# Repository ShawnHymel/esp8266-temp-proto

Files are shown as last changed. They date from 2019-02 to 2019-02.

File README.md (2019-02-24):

ESP8266 Temperature Sensor Prototype
====================================

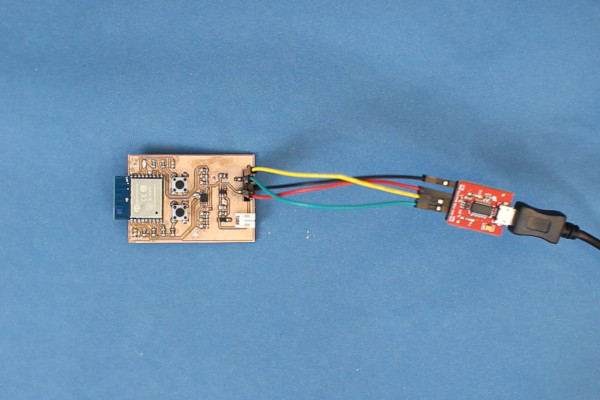
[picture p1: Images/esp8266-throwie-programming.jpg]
ESP8266-WROOM-02 Temperature Sensor Throwie


This is a quick prototype designed for the Bantam Tools Desktop PCB Milling Machine. It uses an ESP8266-WROOM-02 module connected to an MCP9808 temperature sensor. It will run off a single-cell LiPo battery, but there is no protection, undervoltage detection, or charge circuitry onboard. The idea is simple: read from temperature sensor and post to a server at regular intervals. It should work as a simple, IoT Temperature Sensor Throwie.

To Build
--------

Schematic found at *Hardware/esp8266-temp-sensor-schematic.pdf*.

Gerbers are found in the *Hardware/gerbers* folder. Mill them or send them off to a PCB fab house. If you want solder mask and silk screen, you'll have to run your own Gerbers from within KiCad. Also, I didn't move the REFDES labels around to make them look nice (since I was making this board on a mill). You'll probably want to do that, too.

Bill of Materials (BOM) is *Hardware/esp8266-temp-proto_BOM.xlsx*. Buy stuff listed in that. Assemble board.

To Program ESP8266
------------------

Connect 3.3V USB-to-Serial adapter to header on board:

| USB-to-Serial | ESP8266 Board |
| --- | --- |
| 3.3 V | 3.3 V |
| GND | GND |
| TX | RX |
| RX | TX |

Press and hold both buttons. Release RESET button first for 1 second and then release PROG button. This will put the ESP8266 into programming/bootloader mode.

Add `http://arduino.esp8266.com/stable/package_esp8266com_index.json` to the Additional Boards Manager URLs in *File > Preferences in Arduino*. Install *esp8266 by ESP8266 Community* in Boards Manager.

Open *Firmware/esp8266-temp-get/esp8266-temp-get.ino* and change SSID and WiFi password to your network's credentials. Change `hostname` to your computer's IP address. Upload to ESP8266-WROOM-02.

To Run Server
-------------

Install Python (this was tested on Python 3.7). Run *Software/test-srever.py*. With your server running and ESP8266 powered, you should see temperature posted every ~10 seconds.

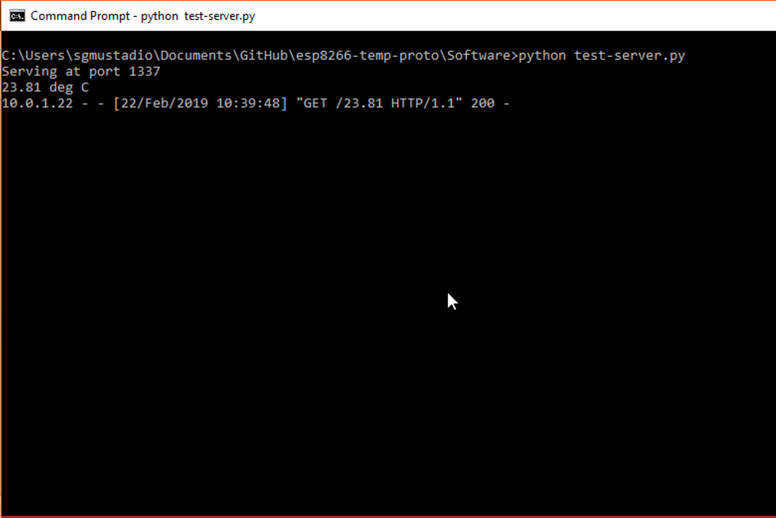
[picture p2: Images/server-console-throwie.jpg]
Temperature Sensor Throwie posting to server console


LED Blink Codes
---------------

Slow blink: Connecting to WiFi

Fast blink: Error

Steady on: Posting to server

License
-------

The hardware (schematic and PCB layout) is licensed under Creative Commons 4.0 BY [CC BY 4.0](https://creativecommons.org/licenses/by/4.0/).

The software (Arduino and Python code found in Firmware/ and Software/) is [Beerware](https://en.wikipedia.org/wiki/Beerware).

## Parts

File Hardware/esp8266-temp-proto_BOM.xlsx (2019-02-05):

Reference | Quantity | Value | Footprint | MPN | Price | Total Price | Part Page
C1 | 1 | 1uF | Capacitor_SMD:C_0805_2012Metric_Pad1.15x1.40mm_HandSolder | 08053C105KAT2A | $0.29 | $0.29 | https://www.digikey.com/product-detail/en/avx-corporation/08053C105KAT2A/478-5030-1-ND/1888241
C2 | 1 | 2.2uF | Capacitor_SMD:C_0805_2012Metric_Pad1.15x1.40mm_HandSolder | 08053C225K4Z2A | $0.47 | $0.47 | https://www.digikey.com/product-detail/en/avx-corporation/08053C225K4Z2A/478-12141-1-ND/9374710
C3 C4 | 2 | 0.1uF | Capacitor_SMD:C_0805_2012Metric_Pad1.15x1.40mm_HandSolder | 08055C104KAT2A | $0.22 | $0.44 | https://www.digikey.com/product-detail/en/avx-corporation/08055C104KAT2A/478-1395-1-ND/564427
D1 | 1 | D_Schottky | Diode_SMD:D_SOD-123F | MBR120VLSFT3G | $0.42 | $0.42 | https://www.digikey.com/product-detail/en/on-semiconductor/MBR120VLSFT3G/MBR120VLSFT3GOSCT-ND/3487322
D2 | 1 | LTST-C171KRKT | digikey-footprints:0805 | LTST-C171KRKT | $0.31 | $0.31 | https://www.digikey.com/product-detail/en/lite-on-inc/LTST-C171KRKT/160-1427-1-ND/386800
J1 | 1 | Conn_01x05 | Connector_PinSocket_2.54mm:PinSocket_1x05_P2.54mm_Vertical_SMD_Pin1Left | NPTC051KFXC-RC | $0.86 | $0.86 | https://www.digikey.com/product-detail/en/sullins-connector-solutions/NPTC051KFXC-RC/S5597-ND/776055
J2 | 1 | S2B-PH-K-S(LF)(SN) | S2B-PH-K-S_LF__SN_:JST_S2B-PH-K-S(LF)(SN) | S2B-PH-K-S(LF)(SN) | $0.17 | $0.17 | https://www.digikey.com/product-detail/en/jst-sales-america-inc/S2B-PH-K-S-LF-SN/455-1719-ND/926626
R1 | 1 | 220 | Resistor_SMD:R_0805_2012Metric_Pad1.15x1.40mm_HandSolder | RC0805FR-07220RL | $0.10 | $0.10 | https://www.digikey.com/product-detail/en/yageo/RC0805FR-07220RL/311-220CRCT-ND/730688
R10 R11 R12 R13 R2 R5 R7 R8 R9 | 9 | 10k | Resistor_SMD:R_0805_2012Metric_Pad1.15x1.40mm_HandSolder | RC0805FR-0710KL | $0.10 | $0.90 | https://www.digikey.com/product-detail/en/yageo/RC0805FR-0710KL/311-10.0KCRCT-ND/730482
R3 R4 | 2 | 4.7k | Resistor_SMD:R_0805_2012Metric_Pad1.15x1.40mm_HandSolder | RC0805FR-074K7L | $0.10 | $0.20 | https://www.digikey.com/product-detail/en/yageo/RC0805FR-074K7L/311-4.70KCRCT-ND/730876
R6 | 1 | 1k | Resistor_SMD:R_0805_2012Metric_Pad1.15x1.40mm_HandSolder | RC0805FR-071KL | $0.10 | $0.10 | https://www.digikey.com/product-detail/en/yageo/RC0805FR-071KL/311-1.00KCRCT-ND/730391
S1 S2 | 2 | 1825910-6 | digikey-footprints:Switch_Tactile_THT_6x6mm | 1825910-6 | $0.11 | $0.22 | https://www.digikey.com/product-detail/en/te-connectivity-alcoswitch-switches/1825910-6/450-1650-ND/1632536
U1 | 1 | AP2112K-3.3TRG1 | AP2112K-3.3TRG1:SOT95P285X140-5N | AP2112K-3.3TRG1 | $0.49 | $0.49 | https://www.digikey.com/product-detail/en/diodes-incorporated/AP2112K-3.3TRG1/AP2112K-3.3TRG1DICT-ND/4505257
U2 | 1 | MCP9808-E_MS | MCP9808-E&slash_MS:MCP9808-E&slash_MS | MCP9808-E/MS | $1.16 | $1.16 | https://www.digikey.com/product-detail/en/microchip-technology/MCP9808-E-MS/MCP9808-E-MS-ND/2802083
U3 | 1 | ESP-WROOM-02 | ESP-WROOM-02:MODULE_ESP-WROOM-02 | ESP-WROOM-02 | $2.70 | $2.70 | https://www.digikey.com/product-detail/en/espressif-systems/ESP-WROOM-02/1904-1009-1-ND/8544304
 |  |  |  |  | Total: | $8.83

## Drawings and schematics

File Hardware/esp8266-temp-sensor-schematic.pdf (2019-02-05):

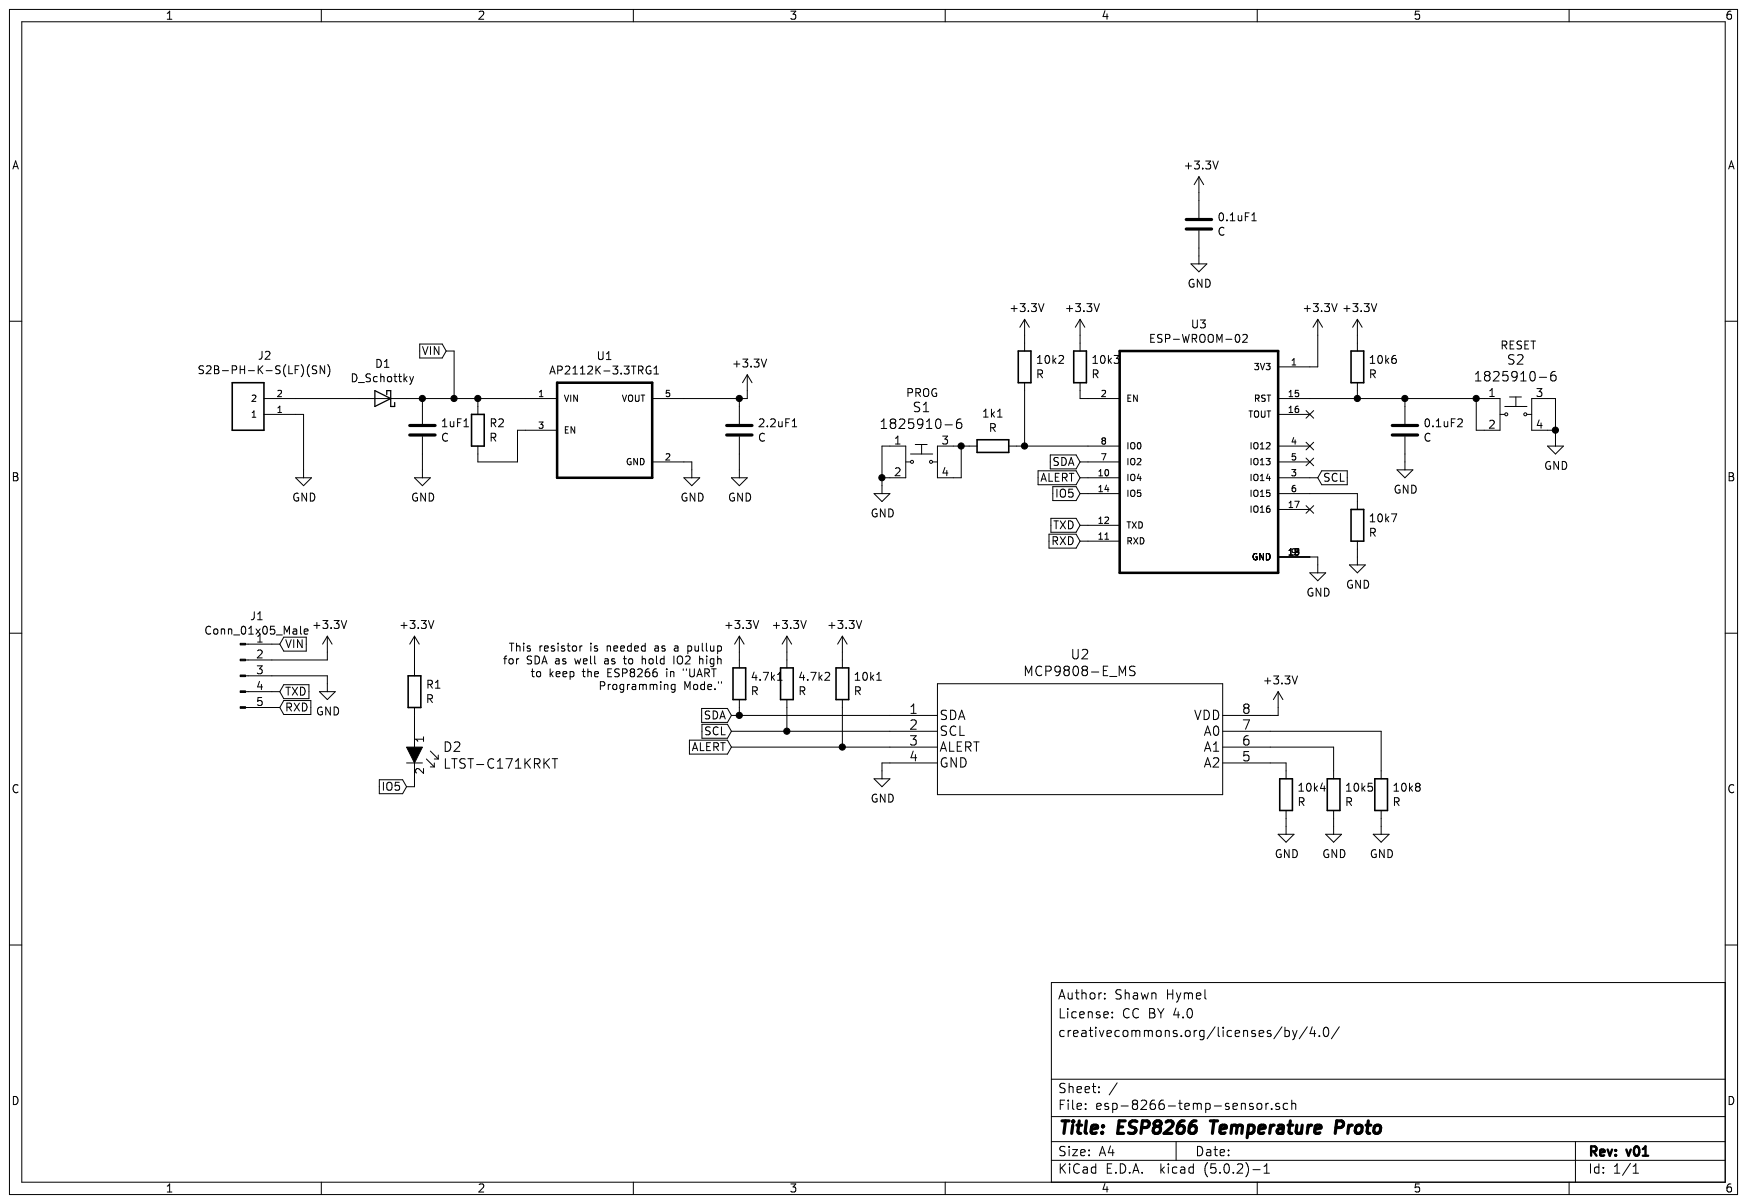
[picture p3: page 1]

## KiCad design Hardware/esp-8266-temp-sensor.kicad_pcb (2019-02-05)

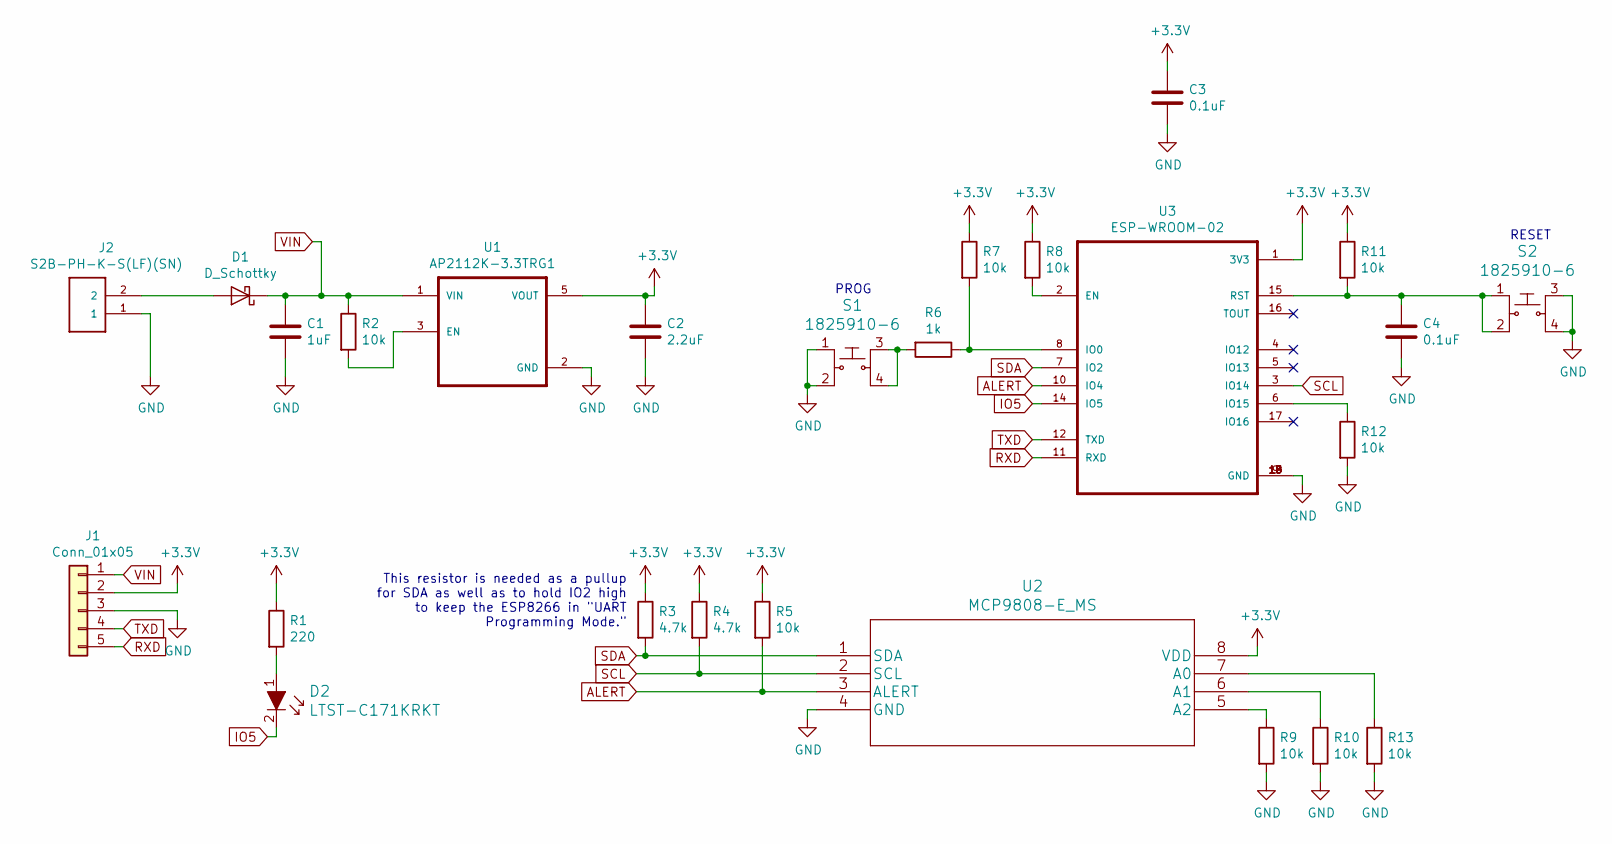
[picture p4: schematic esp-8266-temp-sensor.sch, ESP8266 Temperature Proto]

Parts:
C1: 1uF; C_0805_2012Metric_Pad1.15x1.40mm_HandSolder
C2: 2.2uF; C_0805_2012Metric_Pad1.15x1.40mm_HandSolder
C3, C4: 0.1uF; C_0805_2012Metric_Pad1.15x1.40mm_HandSolder
D1: D_Schottky; D_SOD-123F
D2: LTST-C171KRKT; 0805; MPN LTST-C171KRKT; Digi-Key_PN 160-1427-1-ND
J1: Conn_01x05; PinSocket_1x05_P2.54mm_Vertical_SMD_Pin1Left
J2: S2B-PH-K-S(LF)(SN); JST_S2B-PH-K-S(LF)(SN)
R1: 220; R_0805_2012Metric_Pad1.15x1.40mm_HandSolder
R2, R5, R7, R8, R9, R10, R11, R12, R13: 10k; R_0805_2012Metric_Pad1.15x1.40mm_HandSolder
R3, R4: 4.7k; R_0805_2012Metric_Pad1.15x1.40mm_HandSolder
R6: 1k; R_0805_2012Metric_Pad1.15x1.40mm_HandSolder
S1, S2: 1825910-6; Switch_Tactile_THT_6x6mm; MPN 1825910-6; Digi-Key_PN 450-1650-ND
U1: AP2112K-3.3TRG1; SOT95P285X140-5N
U2: MCP9808-E_MS; MCP9808-E&slash_MS
U3: ESP-WROOM-02; MODULE_ESP-WROOM-02

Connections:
+3V3: C2.1, C3.1, J1.2, R1.1, R3.1, R4.1, R5.1, R7.1, R8.1, R11.1, U1.5 (VOUT), U2.8 (VDD), U3.1 (3V3)
ALERT: R5.2, U2.3 (ALERT), U3.10 (IO4)
GND: C1.2, C2.2, C3.2, C4.2, J1.3, J2.1, R9.2, R10.2, R12.2, R13.2, S1.1, S1.2, S2.3, S2.4, U1.2 (GND), U2.4 (GND), U3.9 (GND), U3.13 (GND), U3.18 (GND), U3.19 (GND)
IO5: D2.2, U3.14 (IO5)
unnamed: C4.1, R11.2, S2.1, S2.2, U3.15 (RST)
unnamed: D1.2 (A), J2.2
unnamed: D2.1, R1.2
unnamed: R2.2, U1.3 (EN)
unnamed: R6.1, R7.2, U3.8 (IO0)
unnamed: R6.2, S1.3, S1.4
unnamed: R8.2, U3.2 (EN)
unnamed: R9.1, U2.5 (A2)
unnamed: R10.1, U2.6 (A1)
unnamed: R12.1, U3.6 (IO15)
unnamed: R13.1, U2.7 (A0)
RXD: J1.5, U3.11 (RXD)
SCL: R4.2, U2.2 (SCL), U3.3 (IO14)
SDA: R3.2, U2.1 (SDA), U3.7 (IO2)
TXD: J1.4, U3.12 (TXD)
VIN: C1.1, D1.1 (K), J1.1, R2.1, U1.1 (VIN)

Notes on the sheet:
This resistor is needed as a pullup for SDA as well as to hold IO2 high to keep the ESP8266 in "UART Programming Mode."
PROG
RESET

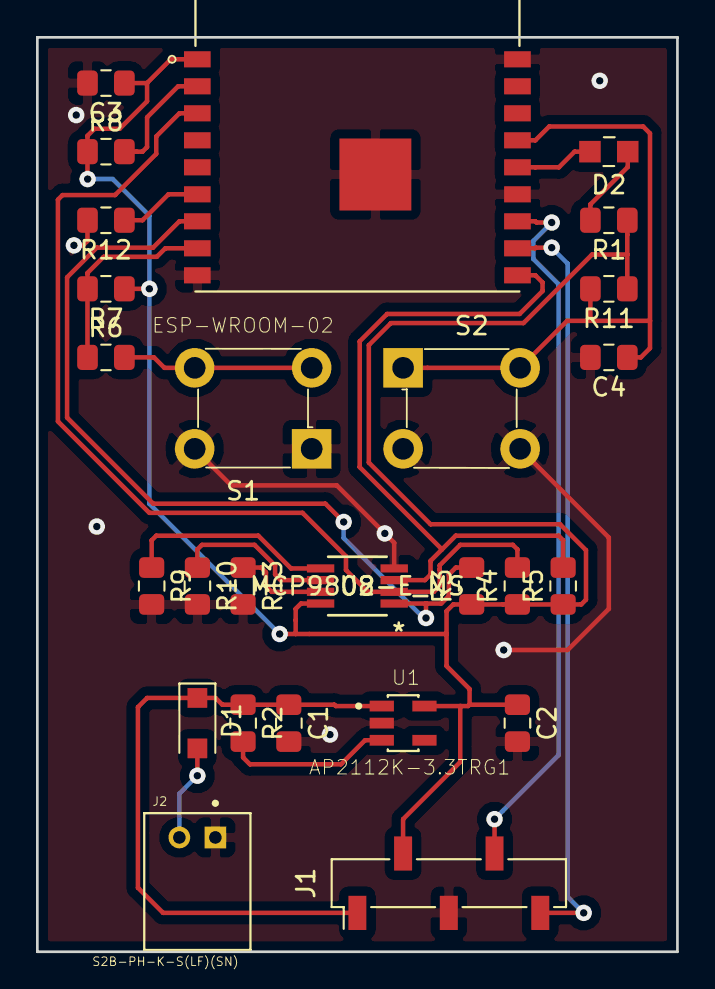
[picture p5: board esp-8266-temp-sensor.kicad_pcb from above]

Board: 2 copper layers, 35.6 x 50.8 mm, 26 parts (0 on the bottom side), 20 nets.

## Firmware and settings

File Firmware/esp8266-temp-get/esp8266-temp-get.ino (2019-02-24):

/**
 * ESP8266-WROOM-02 Temperature Test
 * 
 * Author: Shawn Hymel
 * Date: February 19, 2019
 * 
 * Sends temperature data (Celsius) to specified 
 * webserver via HTTP GET request:
 * 
 *   http://<hostname>/xx.yy
 *   
 * Where <hostname> is hostname variable and
 * xx.yy is temperature (Celsius to 2 decimal
 * places).
 * 
 * I2C Temperature sensor: MCP9808
 * 
 * License: Beerware
 * As long as you retain this notice you can do 
 * whatever you want with this stuff. If we meet 
 * some day, and you think this stuff is worth it, 
 * you can buy me a beer in return
 */

#include <ESP8266WiFi.h>
#include <Wire.h>
#include "Adafruit_MCP9808.h"

// Parameters
const char ssid[] = "<YOUR SSID>";
const char password[] = "<YOUR WIFI PASSWORD>";

// Server, file, and port
const char hostname[] = "<YOUR SERVER'S IP ADDR>";
const int port = 1337;

// How long we want to wait between requests (ms)
const int sleep_ms = 10000;

// Pins
const int LED_PIN = 5;
const int SDA_PIN = 2;
const int SCL_PIN = 14;

// MCP9808 temperature sensor I2C address
const int TEMP_I2C_ADDR = 0x18;

// WiFi client
WiFiClient client;

// Temperature sensor object
Adafruit_MCP9808 temp_sensor = Adafruit_MCP9808();

void setup() {

  // Configure LED. Remember, HIGH is off.
  pinMode(LED_PIN, OUTPUT);
  digitalWrite(LED_PIN, HIGH);

  // Configure I2C pins
  Wire.begin(SDA_PIN, SCL_PIN);

  // Initialize temperature sensor
  if ( !temp_sensor.begin(TEMP_I2C_ADDR) ) {

    // Blink rapidly forever on error
    while (1) {
      blink(1, 100);
    }
  }

  // Set temperature sensor to maximum resolution
  temp_sensor.setResolution(3);

  //  Force the ESP into client-only mode
  WiFi.mode(WIFI_STA); 

  //  Enable light sleep
  wifi_fpm_set_sleep_type(LIGHT_SLEEP_T);

  // Connect to WiFi (blink while connecting)
  WiFi.begin(ssid, password);
  while ( WiFi.status() != WL_CONNECTED ) {
    blink(1, 500);
  }
}

void loop() {

  // Turn on LED to show that we are posting temp
  digitalWrite(LED_PIN, LOW);

  // Wake up temperature sensor and take reading
  temp_sensor.wake();
  float temp_c = temp_sensor.readTempC();

  // Construct URI from temperature value
  String temp_uri = "/" + String(temp_c, 2);

  // Connect to server (blink 3 times on error)
  if ( client.connect(hostname, port) == 0 ) {
    blink(3, 200);
  }

  // Send request
  client.print("GET " + temp_uri + 
                " HTTP/1.1\r\n" +
                "Host: " + hostname + "\r\n" +
                "Connection: close\r\n" +
                "\r\n");
  //delay(500);

  // Shut down client
  client.stop();

  // Put temperature sensor to sleep
  temp_sensor.shutdown_wake(1);

  // Turn off LED to show that we are done
  digitalWrite(LED_PIN, HIGH);

  delay(sleep_ms);
}

// Blink a number of times with given delay
void blink(int times, int delay_ms) {
  for ( int i = 0; i < times; i++ ) {
    digitalWrite(LED_PIN, LOW);
    delay(delay_ms);
    digitalWrite(LED_PIN, HIGH);
    delay(delay_ms);
  }
}

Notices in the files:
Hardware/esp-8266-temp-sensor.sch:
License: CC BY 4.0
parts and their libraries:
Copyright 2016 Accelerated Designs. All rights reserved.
